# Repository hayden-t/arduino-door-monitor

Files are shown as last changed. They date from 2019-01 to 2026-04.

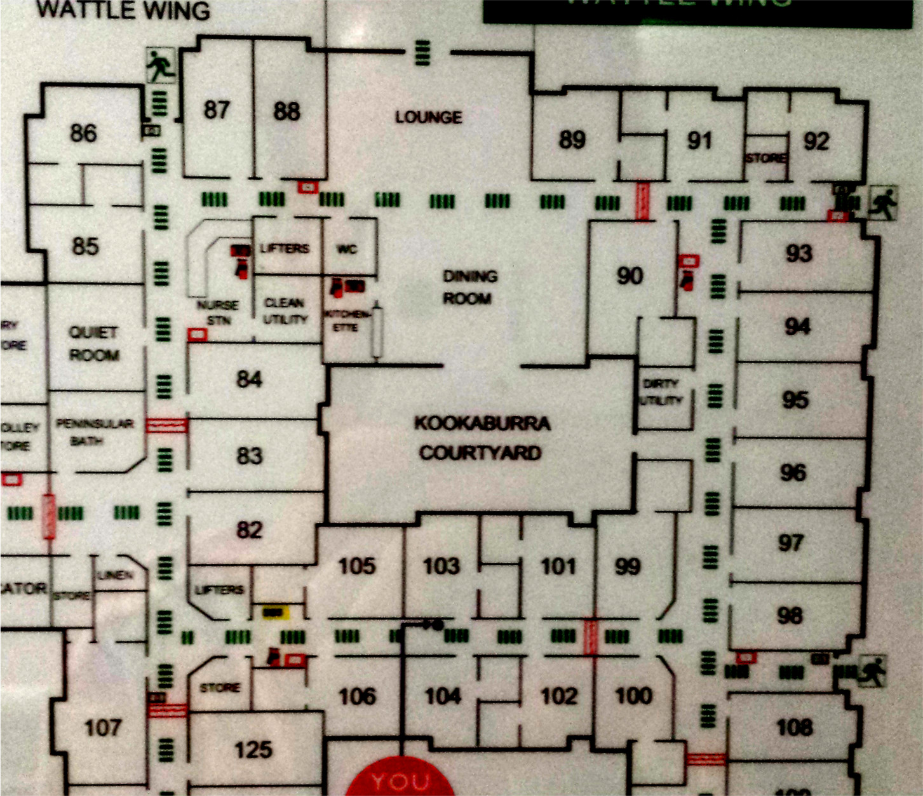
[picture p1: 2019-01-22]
images/wattle.jpg

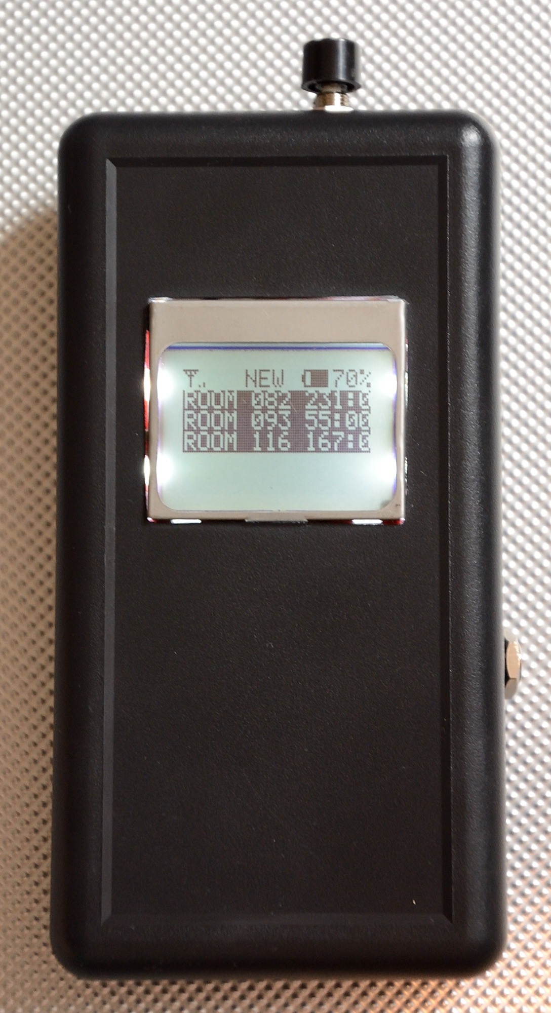
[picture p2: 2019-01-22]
images/DSC_2162.JPG

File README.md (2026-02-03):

# arduino-door-monitor

https://hackaday.io/project/191066-dementia-support-unit-bedroom-door-monitor

An Arduino based alert and logging system, including portable receivers for tracking 30+ room doorway motion sensors.

Folders:

doors_base - source code for the ATmega 256 base unit that collects, logs, displays, alerts and pushes alerts to the mobile units

doors_mobile - source code for the ATmega 328 handheld portable units that receive event broadcasts from the base unit

doors_node - source code for doorway monitor node, discontinued instead to wire the sensors to a shared hub node

doors_relay - source code for the shared node hubs that are wired to the motion sensors and relay event via radio to the hub

hardware - arduino ide board profiles for running a 328 at 1.8v brownout 

images - self explanatory

libraries - all the arduino libraries needed for the source code

pcb - fritzing pcb layouts for the doors_node units

layout.odg - a map of the rooms showing tree network of the different units

manual.odg - a manual for end user reference

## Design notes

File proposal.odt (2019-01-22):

Currently there exists in the roof above each doorway a motion sensor that is connected to the bed sensor control panel by the doorway, and detects movement through the doorway. This is different to the one in the room corner that detects room movement, and activates lights, etc.

The doorway one is rather redundant as any motion it detects is also detected by the room one due to room layout.

A problem in making use of the door one in the existing system is that any motion it detects is only reported on if the doorway control panel is turned on & the resident has gotten out of bed.

Also the door program must be on a setting other than 0 which is the one always used as it is the only program offering immediate notification of resident getting out of bed.

The existing system support 5 sensors of which 4 you are using, and it's made to be able to run without all 5, so disconnecting the poorly utilised door one will not be a problem.

Austco manufactures the system, (which is resold by AceTek, among others)

Learning more about the existing system and sensors, and spending time in the roof test installing my new system has made me re-think my approach and to recommend considering switching the new system to potentially utilise the existing doorway motion sensors.

Advantages:

- Can monitor the doorway activity regardless of door needing to be closed.
- Sensor data collection can be roof based, so nothing in rooms.
- No need for batteries for door units.
- No need for individual door units.
- Better radio reception between units.

Changes:

- Decide between either disconnecting existing doorway sensor and use them, or add a second one at cost ~$70/room , @ 26 rooms = $1820
- Purchase of 14 additional motion sensors for rooms that don't have them already, ~$980
- Replace individual door monitor units, with one 'group' unit that handles all sensor input for one area, eg corridor.
- Any additional costs (eg wiring & group units) besides new sensors would be offset by not needing the individual door units.

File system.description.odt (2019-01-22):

HTTECH Website and IT

Hayden Thring

0435284227

www.httech.com.au

hayden@httech.com.au

Wattle Door Sensor System:

- 32 Wireless Door Sensors
- 7 Wireless Repeaters
- 1 Base Station with 7” Touch Screen

Features:

- Display status of doors
- Record time of opening & closing of doors
- Display most recently changed doors, and how long ago
- Optional notification/alarm on select door changes
- Store all data on SD memory card

Future expandability:

- Mobile Receiver Units
- Data accessible via network.

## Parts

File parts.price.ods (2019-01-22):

Price Breakdown
 |  | Parts | Labour | Total
 | Stage 1: 5 Sensor, 1 Repeater & Basic Screen | $250.36 | $300.00 | $550.36
 | Stage 2: 32 Sensor Network & Touch Screen | $1,579.87 | $300.00 | $1,879.87
 | Stage 3: Mobile Receiver Units | TBD
 |  |  | TOTAL: | $2,430.23
 | Door Sensor |  |  | $40.06
 | Item | Quantity | Unit | Total
 | Atmega328P-PU Micro-controller | 1 | $6.15 | $6.15
 | 28 Pin DIP IC Socket | 1 | $0.63 | $0.63
 | Battery Holder | 1 | $2.71 | $2.71
 | Battery Clip | 1 | $0.41 | $0.41
 | AA Battery | 2 | $1.00 | $2.00
 | 8Mhz Crystal | 1 | $0.78 | $0.78
 | NRFL01+ Radio Module | 1 | $10.47 | $10.47
 | 22pf Capacitor | 2 | $0.09 | $0.18
 | 10uf Capacitor | 1 | $0.13 | $0.13
 | Reed Switch | 1 | $4.60 | $4.60
 | Plastic Case | 1 | $5.00 | $5.00
 | PCB | 1 | $5.00 | $5.00
 | Headers & Pins | 1 | $2.00 | $2.00
 | Repeater Station |  |  | $50.06
 | Power Regulator | 1 | $5.00 | $5.00
 | Power Transformer | 1 | $5.00 | $5.00
 | Base Station |  |  | $197.89
 | 7” Touch Screen Panel | 1 |  | $64.59
 | Touch Screen Adapter | 1 |  | $12.25
 | Arduino Due | 1 |  | $36.99
 | Larger Case | 1 |  | $25.00
 | Clock Module | 1 |  | $2.00
 | Buzzer | 1 |  | $3.00
 | Switch | 1 |  | $4.00
 | Wattle
 | Sensors | 32 | $40.06 | $1,281.92
 | Repeaters | 7 | $50.06 | $350.42
 | Base Station | 1 | $197.89 | $197.89
 |  |  |  | $1,830.23

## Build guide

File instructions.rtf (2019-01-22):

WIRELESS DOOR MONITOR
Between 7pm & 7am at least one of the portable units must be carried by a staff member.
When anyone goes in or out of a room door in Wattle and High Care the system will alert.
Base on Wattle Desk
Will beep 3 times and show which room and time. Top being most recent.

Mobile Unit
Unplug from charger cord to activate. When not plugged into charger, they will beep continuously until the top button is pressed to acknowledge that you have checked. They will also show which room and time. Top being most recent.

Mobile Unit Charging
Whenever not in use please plug in the charger cord to charge.
If the device has gotten too flat and turned itself off (blank screen), it will need to be plugged into the charger and then turned on to start charging.
To turn on, hold the top button down for 3 seconds.
Screen will display "CHARGING"
Any questions or feedback please speak to the RN or DDON Di Kerr

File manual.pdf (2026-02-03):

## Wireless Doorway Monitor Guide

The following pages should help you understand how to use this system effectively.

Page 2 Latest Event Screen Page 3 Set Custom Alarms
Page 4 Mobile Receiver Use

thank you, Hayden
www.httech.com.au - Web Design & IT
Comments / Feedback / Problems:

Base Station Screen 1 – Latest Events

- Shows a scrollable list of the latest 200 events (movement in a doorway), scroll with the UP/DOWN buttons.
- Shows “Alerted” next to an event that was “Alarmed”, such events are sent to the mobile units.
- Mode: All = All events sent to mobile.
- Mode: Custom = Only doors chosen in screen 2 will be sent to mobile units.

Change Modes

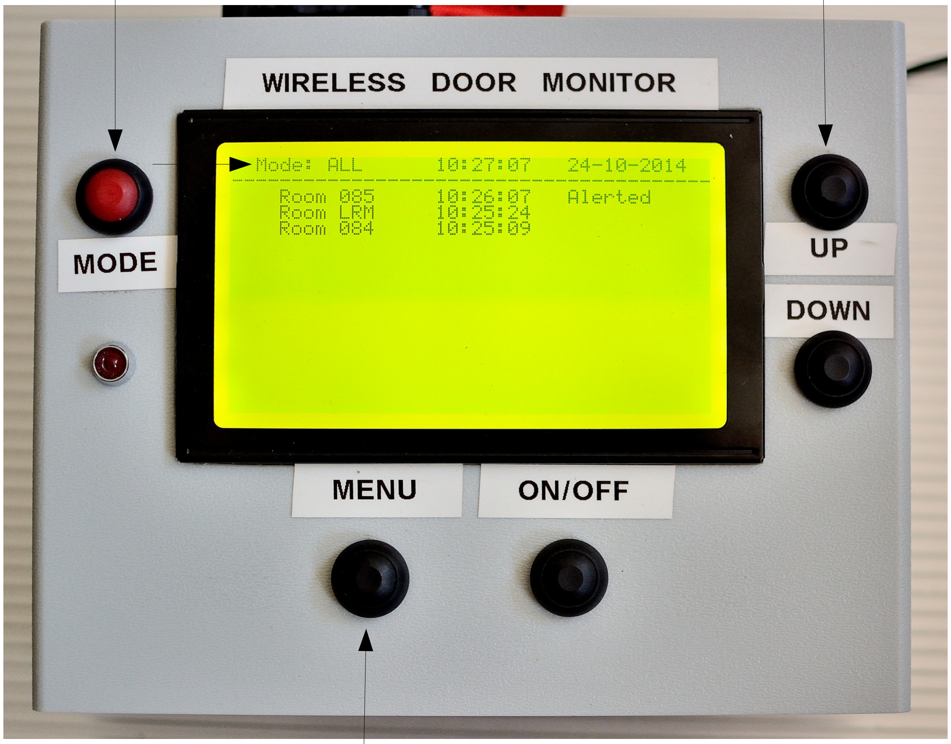
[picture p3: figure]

Switch between screens

Scroll

Base Station Screen 2 – Set Custom Alarms

- Shows a scrollable list of all the doors, scroll & select a door with UP/DOWN buttons, the selected door is shown by the arrow.
- Toggle the “Alarmed” option of a selected door with the “ON/OFF” button.
- Only “Alarmed” doors will be sent to the mobile units when in Mode: Custom

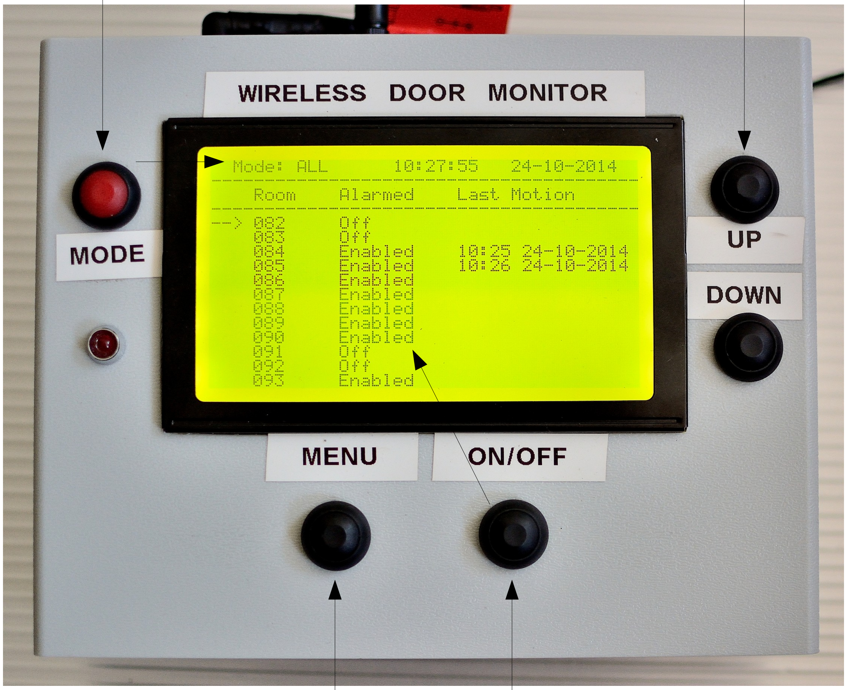
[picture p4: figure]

Switch between screens | Toggle “Alarmed” option
Change Modes | Scroll

Stop Beeping

(Power Hold 5 Sec.)

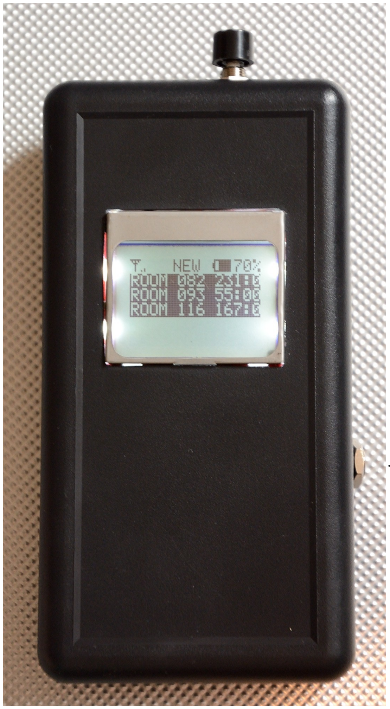
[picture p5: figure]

Charge Plug

Mobile Receiver

- Shows the 5 latest events that the base station has
“alarmed” about.
- Will beep continuously
when a new event is received, press the button to stop it beeping.
- New events are highlighted, and “NEW” is displayed.
- Will also beep once and
display “NO SIGNAL” if out of range.
- To charge, plug lead marked “DOOR MOBILE CHARGER”
in while turned on. Full charge from 0% will take 15 hours, though the charger can be
connected/disconnected at
any time, particularly if still partially charged.

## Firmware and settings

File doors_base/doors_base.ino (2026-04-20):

#include "T6963.h"
#include <RF24Network.h>
#include <RF24.h>
#include <SPI.h>
#include <Wire.h>
#include <RTClib.h>
#include <EEPROM.h>
#include <SdFat.h>
#include <Button.h>
#include "doors.h"
#include "general.h"
#include "settings.h" //wifi settings etc in here

//#define CAST //comment out to not load code
//#define LCD //comment out to not load code
//#define SD //comment out to not load code
//#define REPLIES //print to console replies from ESP

/*
 * setting set in settings.h (rename settings_example.h
 * {"type": "settings","ssid": "WIFI_NAME","password": "","targets":["192.168.1.38"]}
 * example message format:
 * {"type": "doors","door": "Door1"}
 * 
 */

 
//todo make script use this structs

//#define LOW_PA
#define MED_PA

boolean DEBUG = false;

int HOME_TIMEOUT = 30;//seconds

int CAST_EVERY = 10;//seconds between casts;
int CAST_DELAY = 1;//seconds delay between relays;
//maximum total delay between individual relay = CAST_DELAY + CAST_EVERY

const int ALARM_GAP = 3;//seconds ?gap between beeps groups
const int ALARM_COUNT = 3;//seconds ?number of beeps

int LOG_INTERVAL = 60;//only process motion event per x seconds per room


int channel = 84;
const uint16_t root = 00;


const int mobileRelaysCount = 5;
const uint16_t mobileRelays[mobileRelaysCount] = {01, 021, 011, 0111, 01111};

#ifdef SD
//init SD
const uint8_t chipSelect = 8;
SdFat sd;
#endif

#ifdef LCD
//init LCD
T6963 lcd(240,128,6,32);// 240x64 Pixel and 6x8 Font
const int lcdLines = 16;
const int lcdCols = 40;//change printLine() too
char line[lcdCols];
#endif

//init clock
RTC_DS1307 RTC;

// nRF24L01(+) radio attached using Getting Started board 
RF24 radio(9,10);
// Network uses that radio
RF24Network network(radio);

void setup(void)
{
  Serial.begin(115200);
  Serial3.begin(115200);//esp link
  
  Serial.print("[Base Startup] maxEvents:");
  Serial.print(maxEvents);
  Serial.print(" maxDoors:");
  Serial.print(maxDoors);
  Serial.print(" FreeMem: ");
  Serial.println(freeRam());

 
   
  Wire.begin();  
  RTC.begin();
  //RTC.adjust(DateTime(__DATE__, __TIME__).get());//36000 +10 hrs//uncomment and upload once to set clock, comment again and upload after
 
  SPI.begin();    
  
  radio.begin();
  network.begin(channel, root);
    #ifdef LOW_PA 
      radio.setPALevel(RF24_PA_LOW);//-12dbm
    #endif  
    #ifdef MED_PA
      radio.setPALevel(RF24_PA_HIGH);
    #endif
  radio.setDataRate(RF24_250KBPS);  

  Serial.print("[Radio Startup] Address:"); 
  char address[5];
  sprintf(address, "0%o", root);
  Serial.print(address); 
  Serial.print(" CH:");
  Serial.print(channel);
  Serial.print(" PA:");
  Serial.print(radio.getPALevel());
  Serial.print(" DR:");
  Serial.println(radio.getDataRate()); 
  
#ifdef LCD
  lcd.Initialize();
#endif
 
  pinMode(ledPin, OUTPUT);
  pinMode(BUZZER_PIN, OUTPUT);  

  loadSettings();//from Eeprom  

  logEvent(0, 1);

#ifdef LCD
  lcd.TextGoTo(0,3);
  lcd.writeString("   WIRELESS DOOR MONITOR BASE STATION");
  lcd.TextGoTo(0,5);
  lcd.writeString("            www.httech.com.au"); 
  
 #ifdef CAST 
  lcd.TextGoTo(0,9);
  sprintf(line, "           Mobile Sync: %ds", CAST_EVERY);
  printLine(line); 
 #endif

#endif


tone(BUZZER_PIN, 3900, 1000);
digitalWrite(ledPin, HIGH);
delay(1000);

digitalWrite(ledPin, LOW);

#ifdef LCD
  delay(5000);
  lcd.clearText();
  if(exitb.isPressed()){
    Serial.println("Debug Activated");
    DEBUG = true;
    tone(BUZZER_PIN, 3900, 200);
    delay(200);
  }  
#endif



Serial.print("ESP settings sent:");
Serial.println(settings);
Serial3.println(settings);

Serial.print("Example message:");
Serial.println("{\"type\": \"doors\",\"door\": \"Door1\"}");

}//end setup
unsigned long loopTime = 0;
unsigned long buttonTimer = 0;
unsigned long castTimer = 0;
unsigned long castDelay = 0;

int second = 0;
boolean redraw = true;
int mode = 0;
int latestEvent = 0;
int viewEvent = 0;
int menuState = 0;
boolean openMenu = false;

int dst = 0;//daylight savings mode
int nill = dstb.stateChanged();//discard first read

int alarmsPlayed = ALARM_COUNT;

void loop(void)
{

  if(buttonTimer > millis())buttonTimer = millis();//check for overflow
  if(castTimer > millis())castTimer = millis();//check for overflow
  if(castDelay > millis())castDelay = millis();//check for overflow
  
  loopTime = millis();
  DateTime now = RTC.now();
  

  //dst button 
  if(dstb.stateChanged()){//not perfect, does not notice state change when off
      if(dstb.isPressed() && dst==1){
          Serial.println("dst off");
          RTC.adjust(now.get() - 3600);
          EEPROM.write(maxDoors+1, 0);
          dst = 0;
      }else if(dst==0){
          Serial.println("dst on");
          RTC.adjust(now.get() + 3600);
          EEPROM.write(maxDoors+1, 1);
          dst = 1;
      }
  }
  
  if(now.hour() >= 19 || now.hour() < 7)mode = 1;
  else mode = 2;
 // mode = 1;//all
   
  network.update();
  

  // Is there anything ready for us?
  while ( network.available() )
  {
    // If so, grab it and print it out
    RF24NetworkHeader header;
    network.peek(header);

   switch (header.type)
    {
    case 'D'://door
      {
          byte id;
          boolean alarmed;
          
          network.read(header,&id,sizeof(id));          
                  
         if(doors[id].stamp && now.get() - doors[id].stamp < LOG_INTERVAL){
           Serial.print("[Door] Discarding");//only report once per minute per door
           goto reply;
         }

        
         alarmed = ((doors[id].alarm && mode == 2) || (mode == 1) ? true : false );//check the mode   
          
         if(alarmed)alarmsPlayed = 0;
       
          createEvent(id, alarmed);
          
          doors[id].stamp = now.get();   
      
          Serial.print("[Door] ");
          Serial.print("Node: ");
          char address[5];
          sprintf(address, "0%o", header.from_node);
          Serial.print(address);
          Serial.print(" Room: ");
          Serial.print(doors[id].name);

         
          if(alarmed){
            String esp_message =  String("{\"type\": \"doors\",\"door\": \"") + doors[id].name + "\"}";
            Serial3.println(esp_message);//send to esp for wifi broadcast
            Serial.println("Broadcast Door: "+ esp_message);
          }

          reply:
          
             Serial.print(" - Sending Reply: ");
             RF24NetworkHeader response_header( header.from_node, 'R');
             boolean ok = network.write(response_header,&id,sizeof(id));
             if (ok)
                    Serial.println("Ok");
              else{
                    Serial.println("Failed");        
              }
          
       break;
      }
    case 'C'://clear
      {
        
        Serial.print("[Clear]: ");
        cast payload;
        network.read(header,&payload,sizeof(payload));
      
        Serial.print("Id: ");
        Serial.print(payload.id);
        Serial.print(" Door: ");
        Serial.print(doors[payload.id].name);
        Serial.print(" Time: ");
        Serial.print(payload.hours);
        Serial.print(":");
        Serial.print(payload.mins);   
          
        for(int i = 0; i < maxEvents; i++){
          DateTime time (events[i].stamp);
          if( payload.id == events[i].doorId && payload.hours == time.hour() && payload.mins == time.minute() && events[i].alarmed == 1)
          {
                events[i].alarmed = 2;//cleared alarm
                Serial.println(" Found");
                sendEvents(true);
                logEvent(payload.id, 3);
                //break;//found it //find them all
          }
              
        }
        break;
      }
     case 'T'://Test Recieved
     {
             Serial.print("[Test]: Sending Reply, ");
             network.read(header,0,0);
             RF24NetworkHeader response_header( header.from_node, 'Z');
             boolean ok = network.write(response_header,NULL,0);
             if (ok)
                    Serial.println("Ok");
              else{
                    Serial.println("Failed");        
              }        
        break;
    }
    default:
    {
        Serial.println("Unknown Header");
        network.read(header,0,0);
        break;
    }

    };//end switch 
    
  }//end update packet 
  

  checkButtons();
  //checkAlarms();
  checkAlarm();
  //alarm(2);
  
  sendEvents(false);
  
  if(now.second() != second){
      redraw = true;
      second = now.second();
  }
#ifdef LCD  
  if(redraw){
    
    //header
    lcd.TextGoTo(0,0);     

    sprintf(line, "  BEEP: %s   %02d:%02d:%02d   %02d-%02d-%02d", modes[mode],now.hour(), now.minute(), now.second(), now.day(), now.month(), now.year() );

    printLine(line);
    lcd.TextGoTo(0,1);
    lcd.writeString("----------------------------------------");
    //header
    
    if(openMenu)drawMenu();
    else drawEvents();
    redraw = false;
  }

  if(0){
    lcd.TextGoTo(0,0);
    sprintf(line, "%02d", millis() - loopTime);
    lcd.writeString(line);
    delay(500);
  }
#endif

//test script for esp broadcast
  while (Serial.available()) {//pass messages from console to esp
     digitalWrite(LED_BUILTIN, HIGH);
     
     String message = Serial.readString();
     
     Serial.print("Sending ESP: ");
     Serial.println(message);
     Serial3.println(message);
      
     digitalWrite(LED_BUILTIN, LOW);
  }
  
  #ifdef REPLIES
  //print replies from ESP
  while (Serial3.available()) {
     
     String message = Serial3.readString();
     
     Serial.print("ESP: ");
     Serial.println(message);

  }
  #endif
  
 //test script for esp broadcast

}//end loop


void createEvent(byte id, boolean alarmed){


      DateTime now = RTC.now();
      unsigned long adjusted = now.get();
      if(!now.hour() && !now.minute())adjusted =+ 60;//add 1 minute
  
      if(latestEvent == maxEvents)latestEvent = 1;//buffer full, save elsewhere b4 wipe ?
      else latestEvent++;
      
      if(viewEvent != 1 && viewEvent < maxEvents )viewEvent++;//viewing history, increment viewed event
      
      strcpy(events[latestEvent].name, doors[id].name);
      events[latestEvent].stamp = adjusted;
      events[latestEvent].alarmed = (alarmed ? true : false);
      events[latestEvent].doorId = id;
      
      if(alarmed)sendEvents(true);//force cast update

      logEvent(latestEvent, 0);
      redraw = true;
}

void loadSettings(void){
  
  for(int i = 0; i < maxDoors; i++){       
    doors[i].alarm =  (EEPROM.read(i) == 1 ? 1 : 0);
  }
  mode = EEPROM.read(maxDoors);
  if(mode > 2)mode = 0;
  dst = (EEPROM.read(maxDoors+1) == 1 ? 1 : 0);

}

void checkAlarm(){
  
  static unsigned long alarmTimer = millis();
  static int note = 0;
  int noteGap = 150;
  static boolean pause = false;
  
  boolean alarm = false;
  
  
  if(alarmsPlayed < ALARM_COUNT)alarm = true;
  
  if(!alarm){
    pause = false;
    note = 0;
    digitalWrite(ledPin, LOW);
    return;
  }
  
  if(millis() % 1000 < 500)digitalWrite(ledPin, HIGH);
  else digitalWrite(ledPin, LOW);

  
  if(pause){
      if(millis() - alarmTimer > (ALARM_GAP*1000))pause = false;
      else return;
  }

  if(millis() - alarmTimer > noteGap*note){//gap between notes
      switch(note){
           case 0:
               tone(BUZZER_PIN, 3800, 75);
               note++;
               alarmTimer = millis();
             break;     
           case 1:     
               tone(BUZZER_PIN, 3900, 75);
               note++;
             break;
           case 2:     
               tone(BUZZER_PIN, 4000, 75);
               note++;
             break;
           case 3:     
               tone(BUZZER_PIN, 4100, 75);
               note++;     
             break;     
           case 4:
               note = 0;  
               pause = true;
               alarmsPlayed++;
             break;    
           default:
             break;
      }
     
  }

}


void checkButtons(void){
#ifdef LCD  
   //check buttons
 
//down button 
  if(down.uniquePress()){
                     if(!openMenu){
                        if(viewEvent < eventCount())viewEvent++;
                      }else{
                        if(menuState < maxDoors-1)menuState++;
                        else menuState = 0;
                      }   
                      buttonTimer = millis();
                      //Serial.println("Button1");
                      redraw = true;
  }
  
//up button  
   if(up.uniquePress()){
                     if(!openMenu){
                      if(viewEvent > 1)viewEvent--;
                    }else{
                      if(menuState > 0)menuState--;
                      else menuState = maxDoors-1;
                    }    
                      buttonTimer = millis();
                      //Serial.println("Button2");
                      redraw = true;
  }
  
//enter button 
  if(enter.uniquePress()){    
                      if(openMenu)toggleAlarm(menuState);    
                      buttonTimer = millis();
                      //Serial.("Button3");
                      redraw = true;
  }
  
 //menu button 
  if(exitb.uniquePress()){
                       if(!openMenu){openMenu = true;lcd.clearText();}
                      else home();
                       buttonTimer = millis();
                      redraw = true;
  }
  
  //mode button 
  if(modeb.uniquePress()){
//                      changeMode();
//                      buttonTimer = millis();
//                      redraw = true;
  }

  
  if((millis() - buttonTimer) > (HOME_TIMEOUT * 1000) && (viewEvent != 1 || openMenu))home();     
#endif
}
void home(void){
        viewEvent = 1;
        menuState = 0;
        openMenu = false;
#ifdef LCD        
        lcd.clearText();
#endif        
        //Serial.println("Home");
        redraw = true;
}

void toggleAlarm(int menuState){
  
    if(doors[menuState].alarm){
        doors[menuState].alarm = 0;
        EEPROM.write(menuState, 0);
    }
    else{
        doors[menuState].alarm = 1;
        EEPROM.write(menuState, 1);
    }
    
 
}
void drawMenu(void){
 #ifdef LCD 
     //header
         lcd.TextGoTo(0,2);
         sprintf(line, "    Room    Alarmed    Last Motion");
         printLine(line);
         lcd.TextGoTo(0,3);
         lcd.writeString("----------------------------------------");
       //header
  
  for(int i = 0; i < lcdLines-4; i++){

      lcd.TextGoTo(0,i+4);
     
      if(menuState + i < maxDoors){
         DateTime time (doors[menuState + i].stamp); 
         if(doors[menuState + i].stamp){

           sprintf(line, "%s %+3s     %s    %02d:%02d %02d-%02d-%02d" ,(!i ? "-->":"   "), doors[menuState + i].name, (doors[menuState + i].alarm ? "Always ":"Night  "), time.hour(), time.minute(), time.day(), time.month(), time.year());
         }else{
            sprintf(line, "%s %+3s     %s" ,(!i ? "-->":"   "), doors[menuState + i].name, (doors[menuState + i].alarm ? "Always ":"Night  "));

         }
         printLine(line);       
          
      }else emptyLine();
      
   }
#endif
}

void drawEvents(){
#ifdef LCD
//header
/*
    lcd.TextGoTo(0,2);
    sprintf(line, "  Latest       Time     Alerted");
    printLine(line);
    lcd.TextGoTo(0,3);
    lcd.writeString("----------------------------------------");
*/
//header


   for(int i = 0; i < lcdLines-2; i++){
       
        lcd.TextGoTo(0,i+2);
        
        int transEvent = latestEvent - viewEvent - i + 1;
        if(transEvent < 1)transEvent = maxEvents + transEvent;//loop around
        
        if(events[transEvent].stamp == 0){
          emptyLine();
          continue;
        }
      
        DateTime time (events[transEvent].stamp);
        sprintf(line, "    Room %+3s     %02d:%02d:%02d   %02d-%02d-%02d", events[transEvent].name, time.hour(), time.minute(), time.second(),  time.day(), time.month(), time.year());
        printLine(line);      
        
   }
#endif
}

void printLine(char* line){
#ifdef LCD  
  sprintf(line, "%-39s", line);
  lcd.writeString(line);  
#endif
}

void emptyLine(){
#ifdef LCD  
  sprintf(line, "%-39s", "");
  lcd.writeString(line);  
#endif  
}
int eventCount(void){    
  
  if(events[maxEvents].stamp == 0)return latestEvent;
  else return maxEvents;  
  
}

int freeRam ()
{
    extern int __heap_start, *__brkval;
    int v;
    return (int) &v - (__brkval == 0 ? (int) &__heap_start : (int) __brkval);
}

void logEvent(int id, byte type){
 
#ifdef SD
  DateTime time (events[id].stamp);
  if(type)time = RTC.now();
  
  char logName[13];
  sprintf(logName, "%04d%02d%02d.CSV", time.year(), time.month(), time.day());

  char timeString[20];
  sprintf(timeString, "%04d-%02d-%02d %02d:%02d:%02d", time.year(), time.month(), time.day(), time.hour(), time.minute(), time.second());
    
  boolean newLog = false;  
  
  if (!sd.begin(chipSelect, SPI_HALF_SPEED)){
#ifdef LCD
      lcd.clearText();
      lcd.TextGoTo(0,0);
      lcd.writeString("SD ERROR...");
#endif      
      sd.initErrorHalt();
  }

  if(!sd.exists(logName))newLog = true;
    // open stream for append
    ofstream sdout(logName, ios::out | ios::app);
     
   if(newLog)sdout << "NAME,STATUS,ALARMED,TIME" << endl;
       
   switch(type){
      case 0:
             sdout << events[id].name  << ",";
             sdout << "MOTION" << ",";
             if(events[id].alarmed){sdout << "YES" << ",";}else{sdout << "NO" << ",";}
       break;       
      case 1:
           sdout << "SYSTEM,START,NO,";
       break;       
      case 2:
           sdout << "MODE," << modes[mode] << ",NO,";
       break;         
      case 3:
           sdout << doors[id].name << ",CLEAR,NO,";
       break;
    }      
       

       sdout << timeString;
       sdout << endl;

    // close the stream
    sdout.close();
    
#endif

}

void changeMode(void){
      
      mode++;
      if(mode > 2)mode = 0;
      EEPROM.write(maxDoors, mode);
      logEvent(0,2);
     
}

void sendEvents(boolean force){  // cast recent 5 events
#ifdef CAST

  static int currentRelay = 0;
  static boolean queue = false;
  
  if(force){
    Serial.println("[Cast] Queued");
    currentRelay = 0;
    queue = true;
    return;
  }
  
  if(millis() - castDelay < CAST_DELAY * 1000)return;//delay between individual transmissions
  
  if(!queue)if(millis() - castTimer < (CAST_EVERY * 1000))return;//interval between casts
  
   int t = 0;
   
//empty casts
   for(int c = 0; c < maxCast; c++){
       casts[c].id = 0;
       casts[c].hours = 0;
       casts[c].mins = 0;
   }
   
//get recent events
   for(int i = 0; i < maxEvents; i++){
   
     int transEvent = latestEvent - i;
     if(transEvent < 1)transEvent = maxEvents + transEvent;//loop around
   
     if(events[transEvent].alarmed == 1 /*&& events[transEvent].status == 1*/){//uncleared alarmed and door opened
       
       casts[t].id = events[transEvent].doorId;
       
       DateTime time (events[transEvent].stamp);
       casts[t].hours = time.hour();
       casts[t].mins = time.minute();

        t++;
     }
     if(t >= maxCast)break;
   } 
   
//send events
    Serial.print("[Cast] Relay: ");

          char address[5];
          sprintf(address, "0%o", mobileRelays[currentRelay]);

    Serial.print(address);
     
    RF24NetworkHeader header(mobileRelays[currentRelay], 'B');
       
        bool ok = network.write(header, &casts, sizeof(casts));
        Serial.print(" Result: ");
        Serial.println(ok);

    currentRelay++;
    queue = false;  
    castDelay = millis();
    
    if(currentRelay == mobileRelaysCount){//done all relays reset
        currentRelay = 0;
        castTimer = millis();
    }

#endif  
}

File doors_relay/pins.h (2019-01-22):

typedef struct{
  byte id;
  byte pin;
  byte state;
  unsigned long last;
  boolean queue;
} pin;

#ifdef RELAY01
// Address of our node
const uint16_t this_node = 01;
const int numPins = 8;
pin pins[numPins] = {
  {2, 27, 1},//door id //door pin //door state
  {3, 29, 1},
  {4, 31, 1},
  {5, 33, 1},
  {6, 35, 1},
  {7, 37, 1},
  {35, 39, 1},
  {36, 41, 1}
};
#endif

#ifdef RELAY011
// Address of our node
const uint16_t this_node = 011;
const int numPins = 11;
pin pins[numPins] = {
  {0, 27, 1},//door id //door pin //door state
  {1, 29, 1},
  {19, 31, 1},
  {20, 33, 1},
  {21, 35, 1},
  {22, 37, 1},
  {23, 39, 1},
  {24, 41, 1},
  {25, 43, 1},
  {37, 45, 1},
  {38, 47, 1}
};
#endif

#ifdef RELAY021
// Address of our node
const uint16_t this_node = 021;
const int numPins = 5;
pin pins[numPins] = {
  {8, 27, 1},//door id //door pin //door state
  {9, 29, 1},
  {10, 31, 1},
  {11, 33, 1},
  {12, 35, 1}
};
#endif

#ifdef RELAY0111
// Address of our node
const uint16_t this_node = 0111;
const int numPins = 6;
pin pins[numPins] = {
  {13, 27, 1},//door id //door pin //door state
  {14, 29, 1},
  {15, 31, 1},
  {16, 33, 1},
  {17, 35, 1},
  {18, 37, 1}
};
#endif

#ifdef RELAY01111
// Address of our node
const uint16_t this_node = 01111;
const int numPins = 9;
pin pins[numPins] = {
  {26, 27, 1},//door id //door pin //door state
  {27, 29, 1},
  {28, 31, 1},
  {29, 33, 1},
  {30, 35, 1},
  {31, 37, 1},
  {32, 39, 1},
  {33, 41, 1},
  {34, 43, 1}
};
#endif

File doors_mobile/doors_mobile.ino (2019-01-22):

#include <SPI.h>
#include <RF24.h>
#include "printf.h"
#include <LCD5110_Basic.h>
#include <Button.h>
#include "doors.h"
#include "graphics.h"
#include <RunningAverage.h>
#include <EEPROM.h>

int channel = 84;

LCD5110 lcd(4,7,6,8,5);
extern uint8_t SmallFont[];

Button power = Button(2, BUTTON_PULLUP_INTERNAL);
//Button clear = Button(A2, BUTTON_PULLUP_INTERNAL);
//Button menu = Button(A3, BUTTON_PULLUP_INTERNAL);

const int MENU_TIMEOUT = 10 * 1000;
const int LCD_TIMEOUT = 30 * 1000;

const int LOW_VOLTAGE = 0;//%
const int MIN_VOLTAGE = 30;//V

const int RX_TIMEOUT = 2;//delay since last recieve to decrement signal meter
//const int RX_ALERT = 30;//delay since last recieve to alert signal lost
//maximum total delay between individual relay = CAST_DELAY + CAST_EVERY

const unsigned long CHARGE_TIME = 900;//minutes

const int ALARM_GAP = 7;//seconds

const int CHARGE_DETECT = A1;
const int CHARGE_CONTROL = A2;

const int POWER_CONTROL = A3;

const int BUZZER_PIN = A4;

const int LCD_BACKLIGHT = 3;

RunningAverage VOLTAGE(50);

char line[15];

int lcdLines = 6;

typedef struct {
  byte id;
  byte hours;
  byte mins;
} cast;

const int maxCast = 5;

cast casts[maxCast];//used to broadcast
cast oldCast;//used to to compare for new

//cast latestEvent;

const uint64_t pipes[6] = { 0xf04b962d3cLL, 0xf04b962d5aLL, 0xf04b962d69LL, 0xf04b962d96LL, 0xf04b962da5LL, 0xf04b962dc3LL };

const uint64_t readPipe = pipes[0];//mobile pipe number - common to mobile units
//const uint64_t sendPipe = pipes[5];//mobile pipe number - unique to mobile units

RF24 radio(9,10);

unsigned long lastMenu;
int menuState = -1;

unsigned long lastClear;
int charging;
unsigned long chargeTimer;
unsigned long timeLeft;
unsigned long lowVoltTimer;

boolean alarm = false;
boolean connected = false;

void setup(void)
{
  
  //EEPROM.write(0, 2);//save unit number

  Serial.begin(9600);
  printf_begin();
  
  lcd.InitLCD();
  lcd.setFont(SmallFont);
  
  pinMode(LCD_BACKLIGHT, OUTPUT);//lcd backlight
  digitalWrite(LCD_BACKLIGHT, LOW);//lcd backlight  
 
  pinMode(CHARGE_DETECT, INPUT_PULLUP);//charge detect
  pinMode(CHARGE_CONTROL, OUTPUT);//charge control
  digitalWrite(CHARGE_CONTROL, LOW);//charge off  
  
  pinMode(POWER_CONTROL, OUTPUT);//low volt control
  digitalWrite(POWER_CONTROL, HIGH);//low volt control
  
  
  checkCharge();
  power.holdHandler(powerCallback, 3000); // must be held for at least 1000 ms to trigger

  printf("\n\rmobile_rx\n\n\r");
  radio.begin();
  
  radio.setChannel(channel);
 // radio.setPALevel(RF24_PA_LOW);//-12dbm  
  radio.setDataRate(RF24_250KBPS);  
  
  radio.openReadingPipe(1, readPipe);
  radio.setAutoAck(false) ;
  
  radio.powerUp() ;  
  radio.printDetails(); 
  radio.startListening();
  
  sprintf(line, "MOBILE UNIT #%d", EEPROM.read(0));
  lcd.print(line, CENTER, 8); 
  int volts = readVcc();
  sprintf(line, "BATT: %d.%dv", int(volts/10), volts-(int(volts/10)*10));
  lcd.print(line, CENTER, 24); 
 // sprintf(line, "MEM: %d",  freeRam());
 // lcd.print(line, CENTER, 40);
  
   
  chime();
  delay(3000);
  lcd.clrScr();   

 
}
int rx = 0;
unsigned long lastRx;
void loop(void)
{
    if(lastMenu > millis())lastMenu = millis();//check for overflow
    if(lastClear > millis())lastClear = millis();//check for overflow
    if(chargeTimer > millis())chargeTimer = millis();//check for overflow
    if(lowVoltTimer > millis())lowVoltTimer = millis();//check for overflow
    
    if(millis() - lastRx > RX_TIMEOUT * 1000){
        if(rx > 0)rx--;
        else if(connected)signalLost();
        lastRx = millis();
    }
  
    // if there is data ready
    if ( radio.available() )
    {
        
       radio.read(&casts, sizeof(casts));
       
       if(rx == 0){
         Serial.println();
         Serial.print("[Casts] ");         
       }
       
       if(rx < 14)rx++;
       else Serial.println();
       
       lastRx = millis();
       //lcd.print("     ", 21, 0);//remove clear
       connected = true;
        
        Serial.print(rx);
        Serial.print(", ");
       /* int show = 0;
        Serial.print(casts[show].id);
        Serial.print(" ");
        Serial.print(casts[show].status);
        Serial.print(" ");
        Serial.print(casts[show].time);
        Serial.println();       */   
        

        
       /* 
        if(casts[0].id != latestEvent.id || casts[0].hours != latestEvent.hours || casts[0].mins != latestEvent.mins){
          //new event
          if(!charging){
              alarm = true;
              lastMenu = millis();
              latestEvent.id = casts[0].id;
              latestEvent.hours = casts[0].hours;
              latestEvent.mins = casts[0].mins;
          }
        }
        */
    }
    
    checkButtons();    
    checkCharge();
    checkAlarm();
    drawScreen();       
}

void checkButtons(){
 /* if(clear.uniquePress()){
     //sendClear();
     alarm = false;
     lastMenu = millis();
     tone(BUZZER_PIN,4000,50);
  }else if(menu.uniquePress()){
     //shiftMenu();
     alarm = false;
     lastMenu = millis();
     tone(BUZZER_PIN,4000,50);
  }else*/ if(power.uniquePress()){
     lastMenu = millis();
     alarm = false;
     oldCast.id = casts[0].id; oldCast.hours = casts[0].hours; oldCast.mins =  casts[0].mins;
     tone(BUZZER_PIN,4000,50);
  }
  
  power.process();
  
  if(millis() - lastMenu > MENU_TIMEOUT)menuState = -1;
  
  if(millis() - lastMenu > LCD_TIMEOUT){
      digitalWrite(LCD_BACKLIGHT, HIGH);//lcd backlight off
  }else{
      digitalWrite(LCD_BACKLIGHT, LOW);//lcd backlight on
  }
}
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
